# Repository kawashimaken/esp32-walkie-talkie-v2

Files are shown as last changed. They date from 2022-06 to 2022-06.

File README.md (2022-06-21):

# esp32-walkie-talkie-v2

schematics

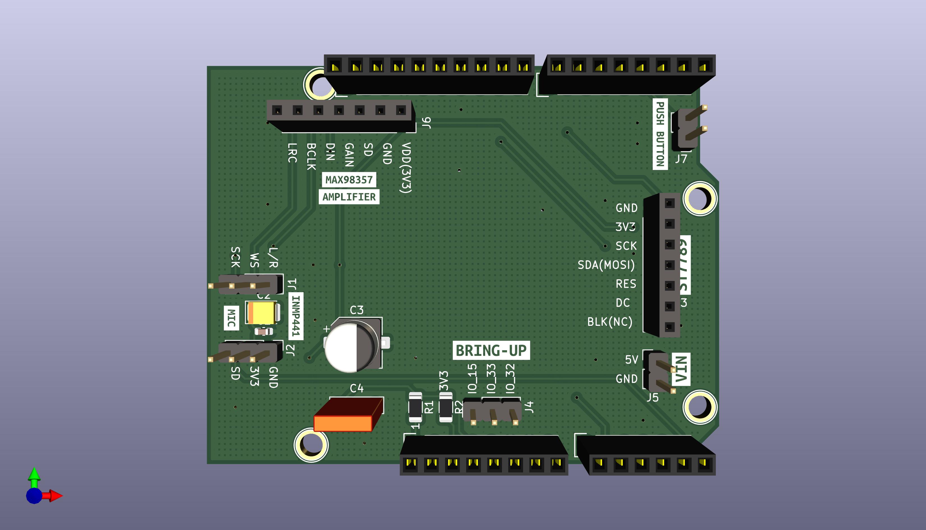
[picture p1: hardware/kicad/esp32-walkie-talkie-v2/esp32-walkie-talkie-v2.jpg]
PCB view


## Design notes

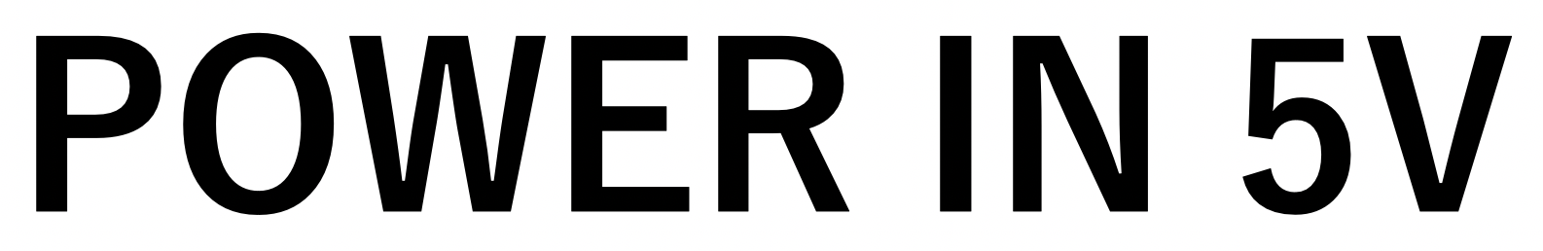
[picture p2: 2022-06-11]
hardware/kicad/esp32-walkie-talkie-v2/silk/power_in_5v.png

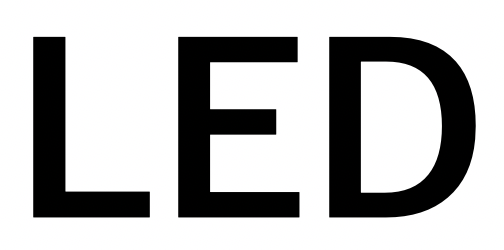
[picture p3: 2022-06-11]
hardware/kicad/esp32-walkie-talkie-v2/silk/led.png

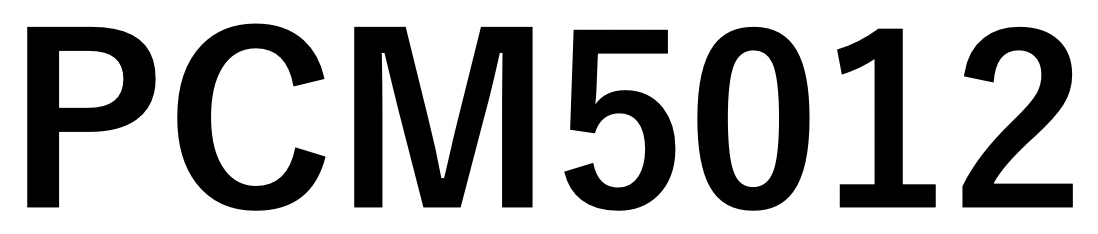
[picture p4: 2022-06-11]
hardware/kicad/esp32-walkie-talkie-v2/silk/pcm5012.png

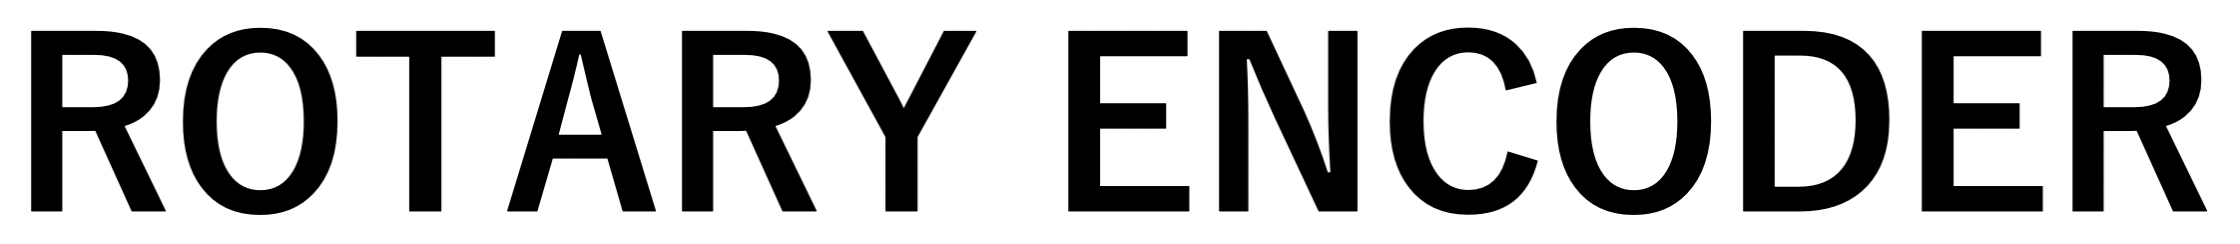
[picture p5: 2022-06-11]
hardware/kicad/esp32-walkie-talkie-v2/silk/rotary_encoder.png

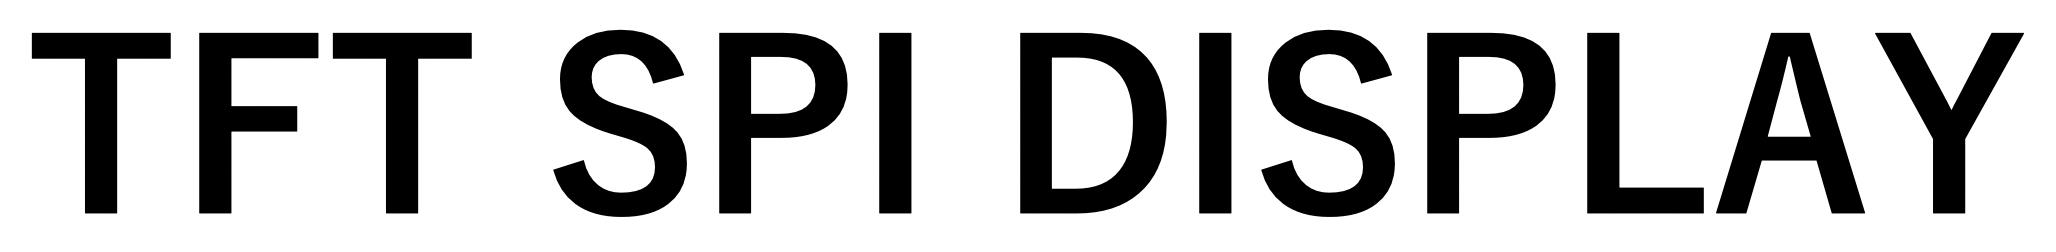
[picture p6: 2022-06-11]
hardware/kicad/esp32-walkie-talkie-v2/silk/tft_spi_display.png

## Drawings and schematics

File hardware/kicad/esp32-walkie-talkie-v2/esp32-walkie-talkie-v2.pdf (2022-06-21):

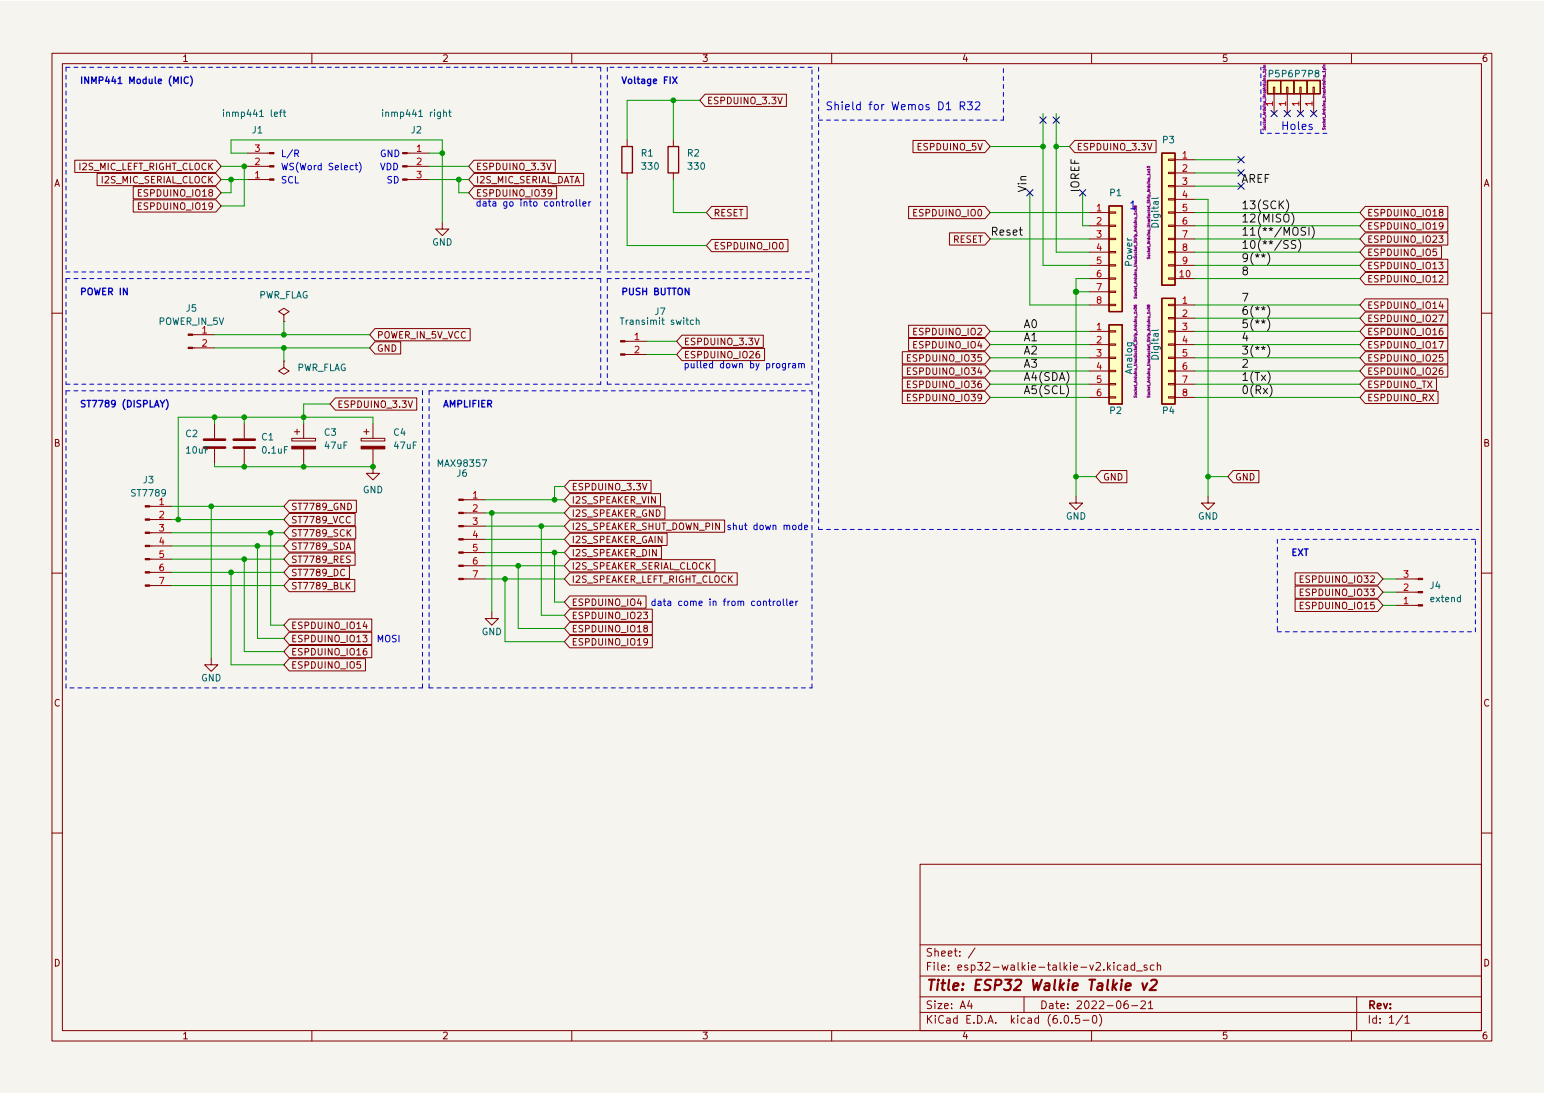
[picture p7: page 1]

data go into controller GND
330 GND
VDD

pulled down by program

File: esp32-walkie-talkie-v2.kicad_sch Sheet: /
Id: 1/1 Title: ESP32 Walkie Talkie v2

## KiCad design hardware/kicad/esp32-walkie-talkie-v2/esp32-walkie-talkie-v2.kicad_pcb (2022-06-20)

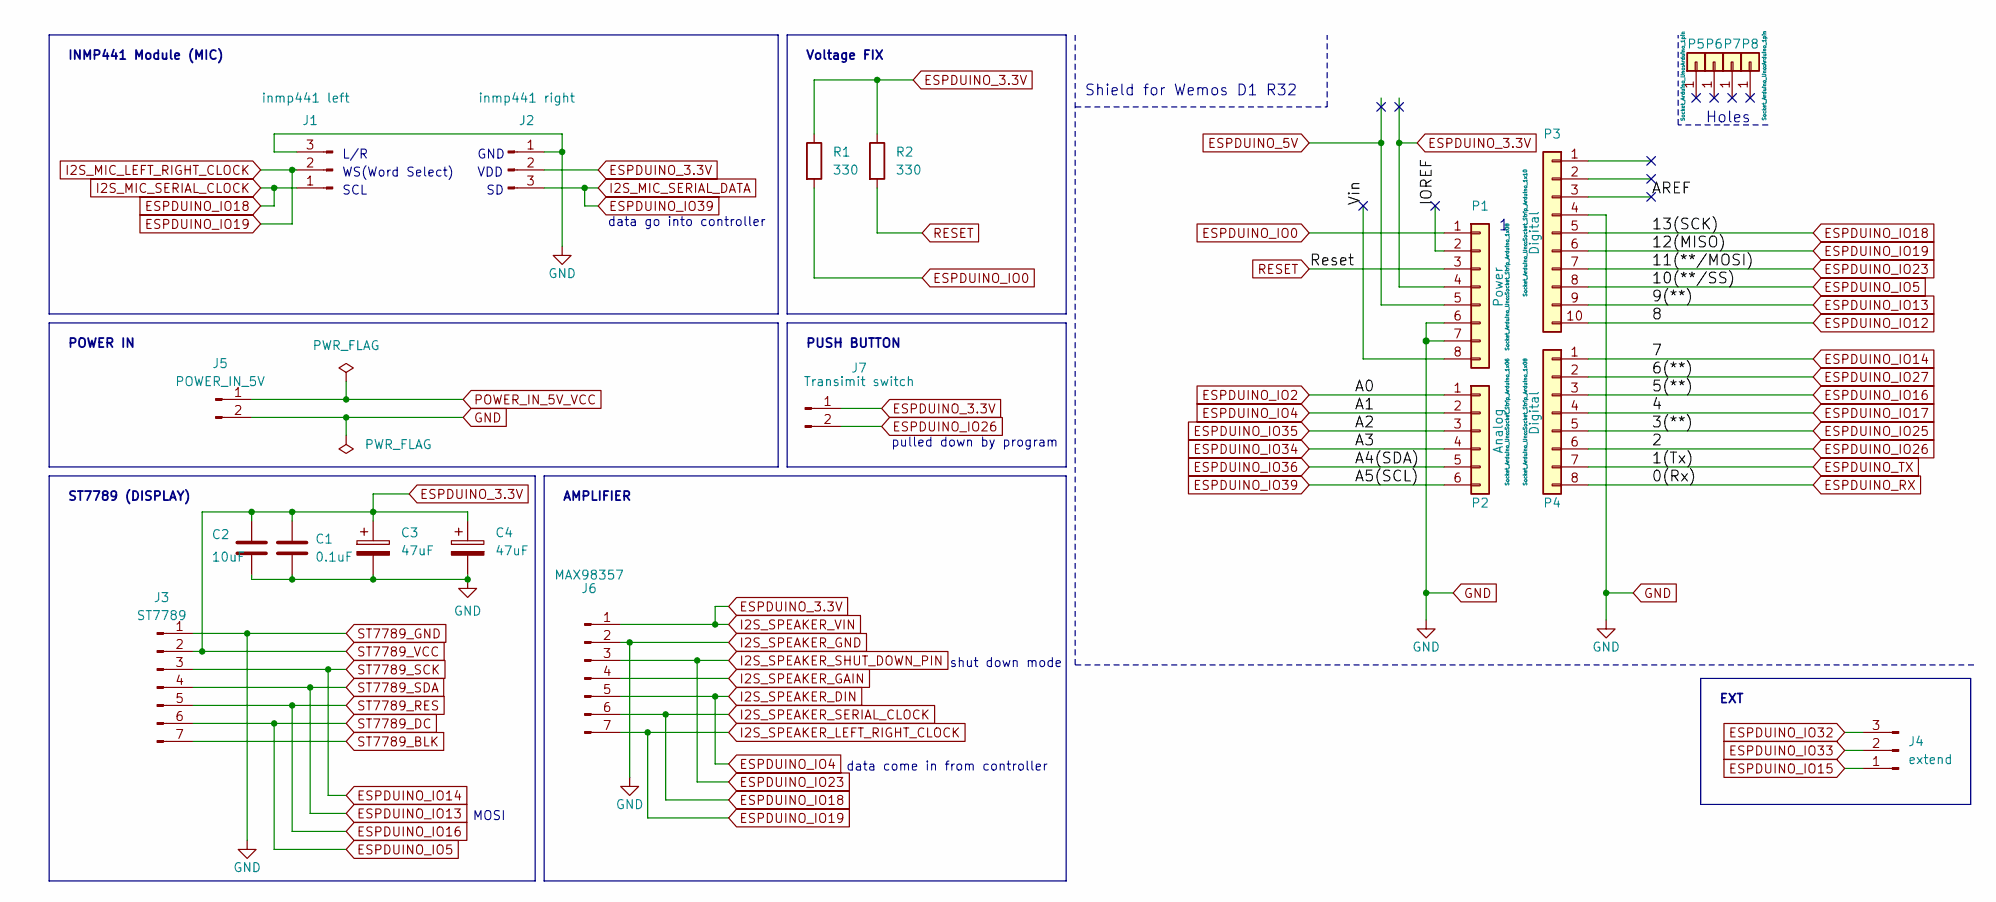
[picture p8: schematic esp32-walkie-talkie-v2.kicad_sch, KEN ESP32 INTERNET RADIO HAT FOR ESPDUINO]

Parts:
C1: 0.1uF; C_0603_1608Metric
C2: 10uF; CP_EIA-3528-12_Kemet-T
C3: 47uF; CP_Elec_6.3x5.8
C4: 47uF; C_Rect_L7.0mm_W2.0mm_P5.00mm
J1: inmp441 left; PinHeader_1x03_P2.54mm_Vertical
J2: inmp441 right; PinHeader_1x03_P2.54mm_Vertical
J3: ST7789; PinSocket_1x07_P2.54mm_Vertical
J4: extend; PinHeader_1x03_P2.54mm_Vertical
J5: POWER_IN_5V; PinHeader_1x02_P2.54mm_Vertical
J6: MAX98357; PinSocket_1x07_P2.54mm_Vertical
J7: Transimit switch; PinHeader_1x02_P2.54mm_Vertical
P1: Power; Socket_Strip_Arduino_1x08
P2: Analog; Socket_Strip_Arduino_1x06
P3: Digital; Socket_Strip_Arduino_1x10
P4: Digital; Socket_Strip_Arduino_1x08
P5, P6, P7, P8: CONN_01X01; Arduino_1pin
R1, R2: 330; R_1206_3216Metric

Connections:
/AREF: P3.3
/IOREF: P1.2
/Vin: P1.8
ESPDUINO_3.3V: C1.1, C2.1, C3.1, C4.1, J2.2, J3.2, J6.1, J7.1, P1.4, R1.1, R2.1
ESPDUINO_5V: P1.5
ESPDUINO_IO0: P1.1, R1.2
ESPDUINO_IO2: P2.1
ESPDUINO_IO4: J6.5, P2.2
ESPDUINO_IO5: J3.6, P3.8
ESPDUINO_IO12: P3.10
ESPDUINO_IO13: J3.4, P3.9
ESPDUINO_IO14: J3.3, P4.1
ESPDUINO_IO15: J4.1
ESPDUINO_IO16: J3.5, P4.3
ESPDUINO_IO17: P4.4
ESPDUINO_IO18: J1.1, J6.6, P3.5
ESPDUINO_IO19: J1.2, J6.7, P3.6
ESPDUINO_IO23: J6.3, P3.7
ESPDUINO_IO25: P4.5
ESPDUINO_IO26: J7.2, P4.6
ESPDUINO_IO27: P4.2
ESPDUINO_IO32: J4.3
ESPDUINO_IO33: J4.2
ESPDUINO_IO34: P2.4
ESPDUINO_IO35: P2.3
ESPDUINO_IO36: P2.5
ESPDUINO_IO39: J2.3, P2.6
ESPDUINO_RX: P4.8
ESPDUINO_TX: P4.7
GND: C1.2, C2.2, C3.2, C4.2, J1.3, J2.1, J3.1, J5.2, J6.2, P1.6, P1.7, P3.4
I2S_SPEAKER_GAIN: J6.4
POWER_IN_5V_VCC: J5.1
RESET: P1.3, R2.2
ST7789_BLK: J3.7

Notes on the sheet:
data go into controller
PUSH BUTTON
data come in from controller
ST7789 (DISPLAY)
EXT
L/R
pulled down by program
POWER IN
Holes
GND
Shield for Wemos D1 R32
AMPLIFIER
SCL
INMP441 Module (MIC)
Voltage FIX
MOSI
VDD
WS(Word Select)
shut down mode

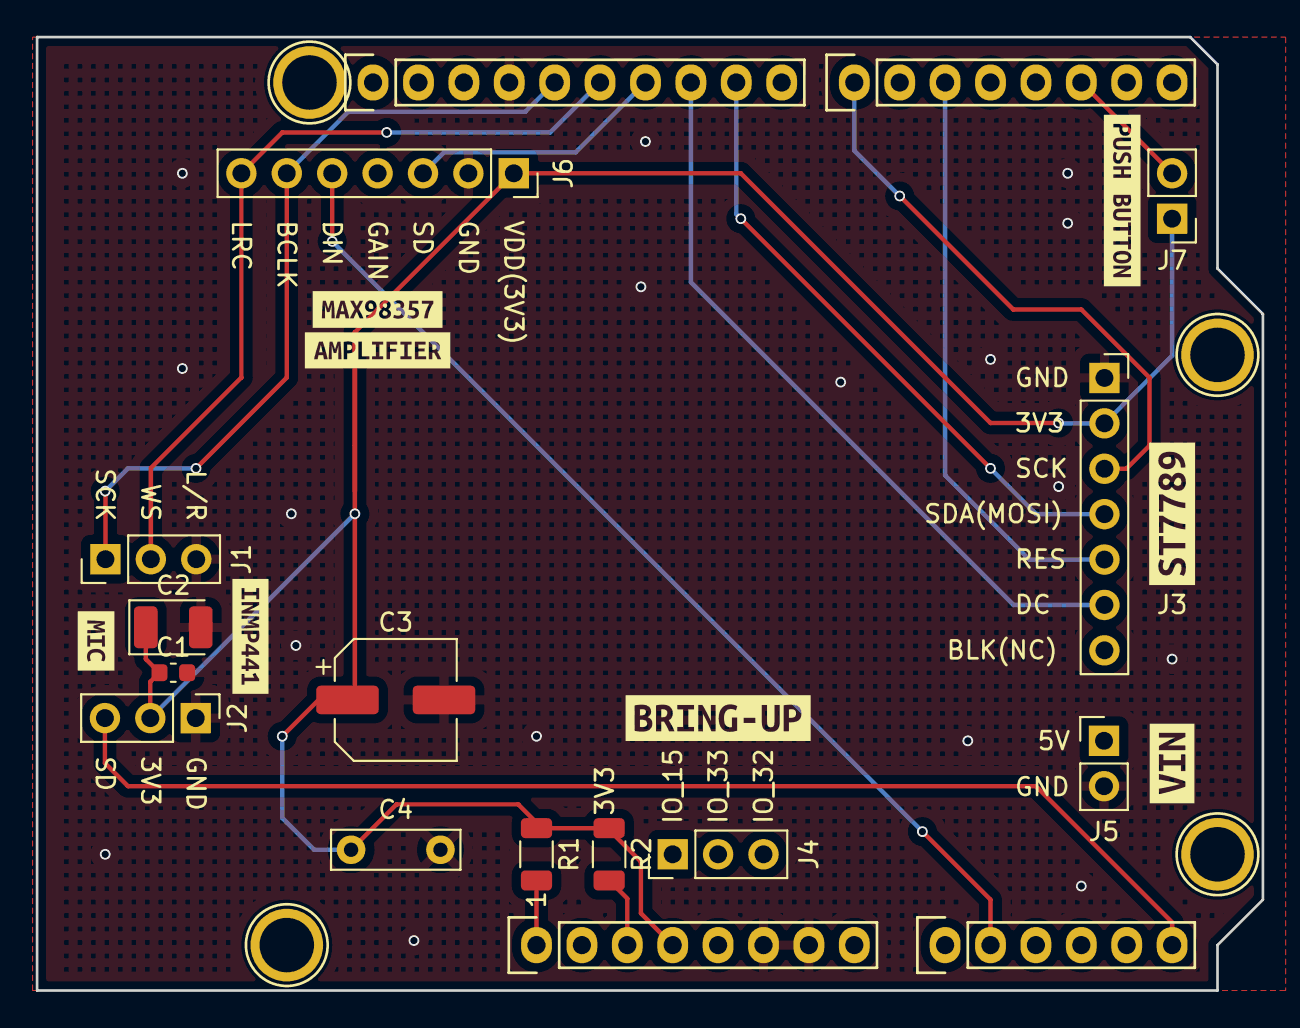
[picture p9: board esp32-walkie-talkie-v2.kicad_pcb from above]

Board: 2 copper layers, 68.6 x 53.3 mm, 29 parts (0 on the bottom side), 14 nets.

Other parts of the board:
kibuzzard-62A4A2A0: G***; kibuzzard-62A4A2A0
kibuzzard-62A4A288: G***; kibuzzard-62A4A288
kibuzzard-62A534F6: G***; kibuzzard-62A534F6
kibuzzard-62A53545: G***; kibuzzard-62A53545
kibuzzard-62A53555: G***; kibuzzard-62A53555
kibuzzard-6279C31F: G***; kibuzzard-6279C31F
kibuzzard-6280E76A: G***; kibuzzard-6280E76A
kibuzzard-6280EDB6: G***; kibuzzard-6280EDB6

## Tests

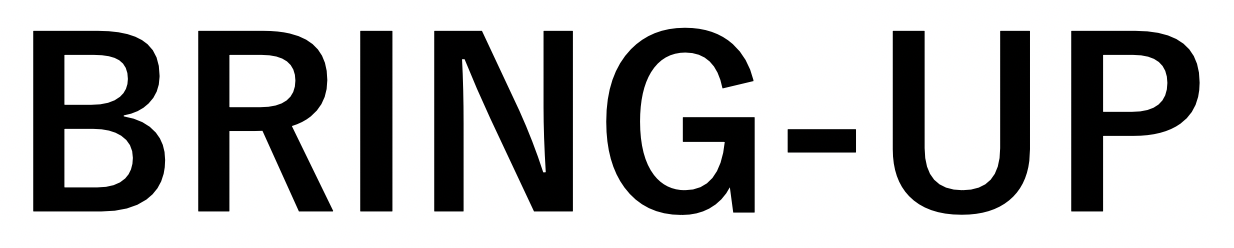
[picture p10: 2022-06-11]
hardware/kicad/esp32-walkie-talkie-v2/silk/bring-up.png

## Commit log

2022-06-11 remove old files
    [esp32-walkie-talkie-v2-B_Cu.gbr, esp32-walkie-talkie-v2-B_Fab.gbr, esp32-walkie-talkie-v2-B_Mask.gbr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]
2022-06-12 update silk, export gerber
    [esp32-walkie-talkie-v2-B_Cu.gbr, esp32-walkie-talkie-v2-B_Fab.gbr, esp32-walkie-talkie-v2-B_Mask.gbr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]
2022-06-12 add option capacitor
    [esp32-walkie-talkie-v2-B_Cu.gbr, esp32-walkie-talkie-v2-B_Fab.gbr, esp32-walkie-talkie-v2-B_Mask.gbr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]
2022-06-12 add rect capacitor option
    [esp32-walkie-talkie-v2-B_Cu.gbr, esp32-walkie-talkie-v2-B_Fab.gbr, esp32-walkie-talkie-v2-B_Mask.gbr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]
2022-06-12 add text, new copper fill
    [esp32-walkie-talkie-v2-B_Cu.gbr, esp32-walkie-talkie-v2-B_Fab.gbr, esp32-walkie-talkie-v2-B_Mask.gbr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]
2022-06-21 send to pcbway
2022-06-21 add schematic pdf
2022-06-21 update svg and pdf
    [esp32-walkie-talkie-v2.kicad_sch]
